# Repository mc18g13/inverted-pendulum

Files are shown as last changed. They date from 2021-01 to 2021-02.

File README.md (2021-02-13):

# rotary-inverted-pendulum



A learning aid for control system design. A rotary inverted pendulum designed with 3d printable frame.

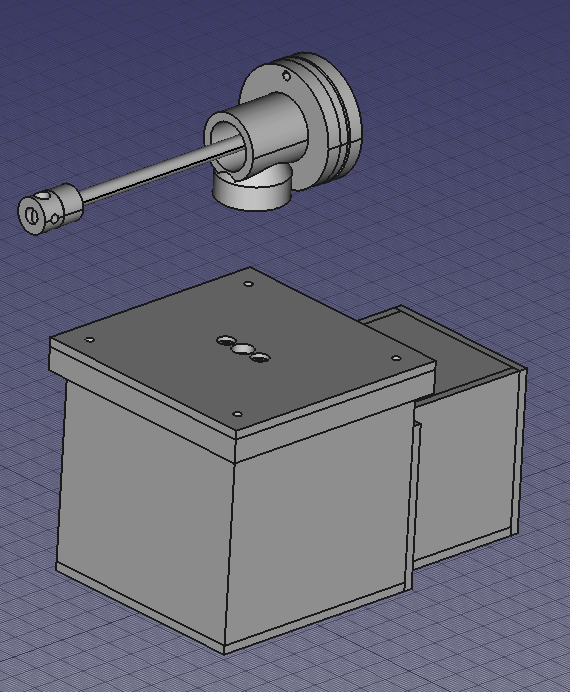
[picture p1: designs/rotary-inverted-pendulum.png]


## Hardware

* Raspberry Pico
* CQRobot 11.7:1 Metal Gearmotor
* L298N motor driver
* AS5600 magnetic encoder
* 5mm diameter steel rod 20cm
* 2 * 625-2RS 5x16x5mm Bearing
* 4 * M3 bolts (box lid)
* 2 * M3 bolts (encoder mount)
* 2 * M3 bolts (pendulum arm mount)
* 2 * M2.5 bolts (motor mount)
* 2 * M4 bolts and nuts (box body mount)
* 3mm flange motor coupling (22mm diameter with 4 M3 bolts)
* Male to Female and Female to Female Jumper wires

# Pico Firmware

This uses docker to setup an image with the required dependencies for building the firmware. Its driven by targets in a makefile as described below

## First Time Setup

This will setup the docker container for building the firmware

```
make
```

## Build
```
make build
```

## Upload
```
make upload
```

## Connect over usb
```
make usb
```

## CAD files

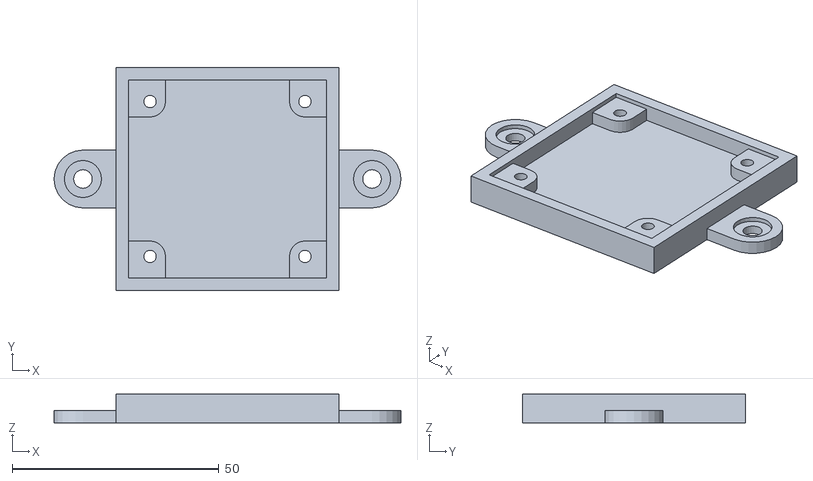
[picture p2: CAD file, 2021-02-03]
designs/cad/l298n/H-Bridge_Mount.stl
84.0 x 54.0 x 7.00

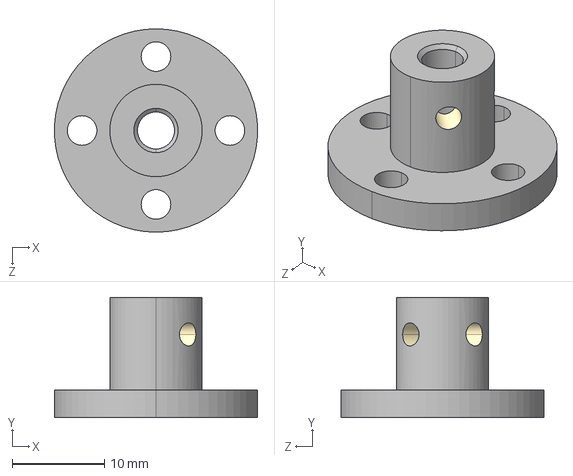
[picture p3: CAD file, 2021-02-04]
designs/cad/motor-coupling/Aluminum Alloy Flange Coupling, 4 mm SHAFT HOLE.STEP
22.0 x 13.0 x 22.0 mm

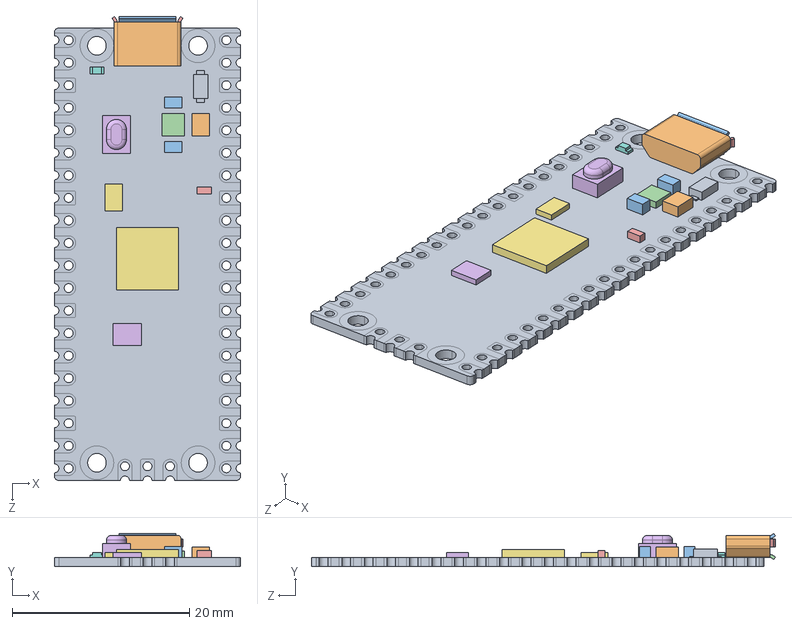
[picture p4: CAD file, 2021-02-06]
designs/cad/pico/Pico-R3.step
21.0 x 3.73 x 52.3 mm
PICO_REF_BOARD.STEP
PICO_REF_USB.STEP
PICO_REF_SWITCH.STEP
PICO_REF_MICROCONTROLLER.STEP
PICO_REF_LED.STEP
PICO_REF_ONSEMI.STEP
PICO_BOURNS.STEP
PICO_MURATA.STEP x 2
PICO_RICHTEK.STEP
PICO_DIODES.STEP
PICO_AEL.STEP
PICO_WINBOND.STEP

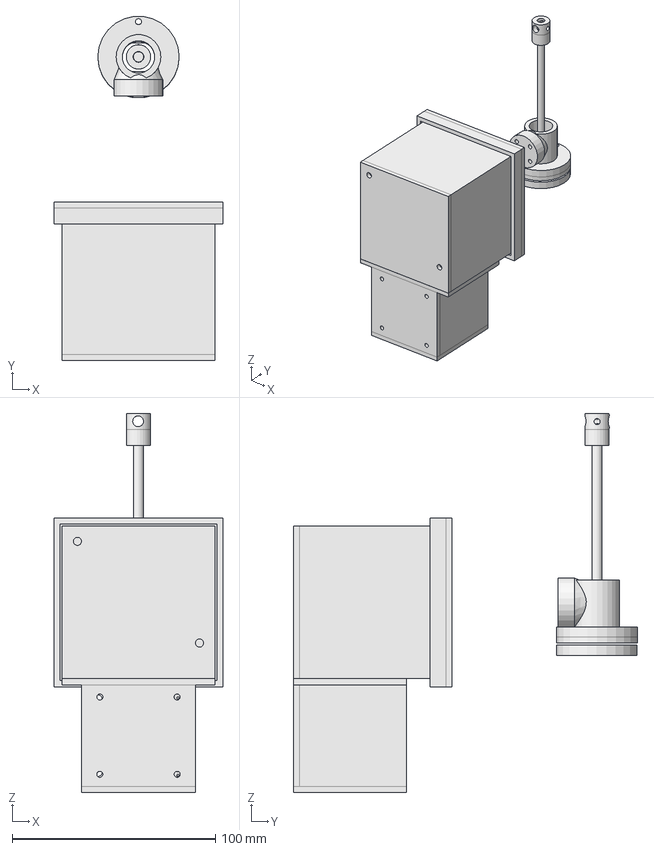
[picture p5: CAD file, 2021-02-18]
designs/cad/rotary-inverted-pendulum.FCStd
83.0 x 169.1 x 186.4 mm
box-lid
motor-box
electronics
motor-arm-connector
L298N_M
PICO_REF_BOARD.STEP

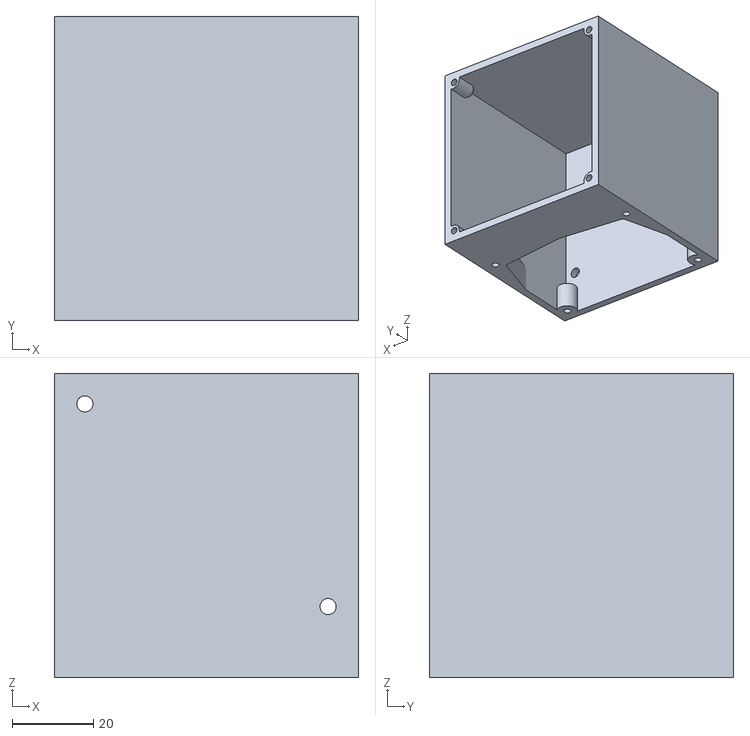
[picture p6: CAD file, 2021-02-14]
designs/cad/motor-box.stl
75.0 x 75.0 x 75.0

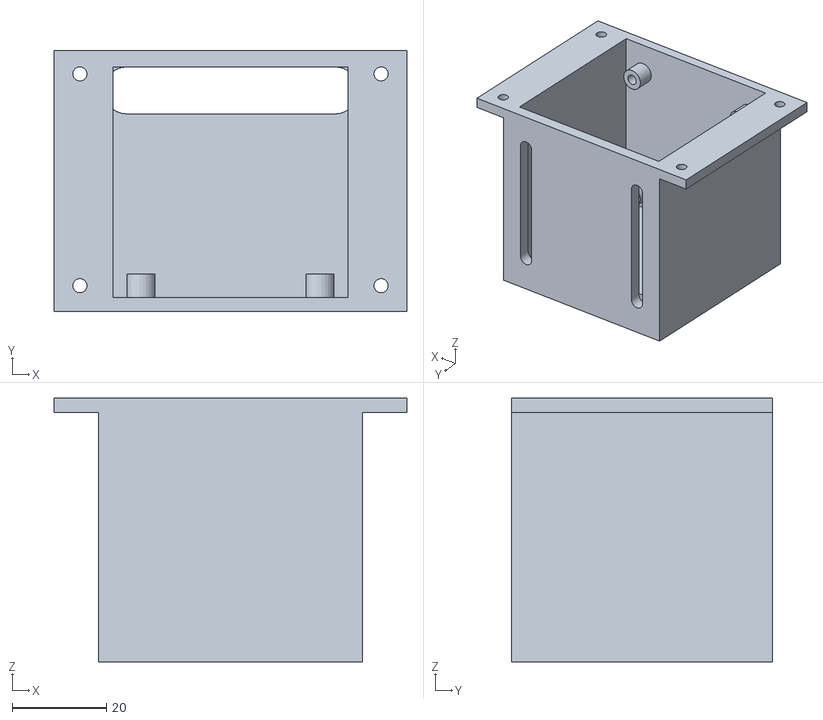
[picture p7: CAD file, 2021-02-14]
designs/cad/electronics-case.stl
75.0 x 55.5 x 56.0

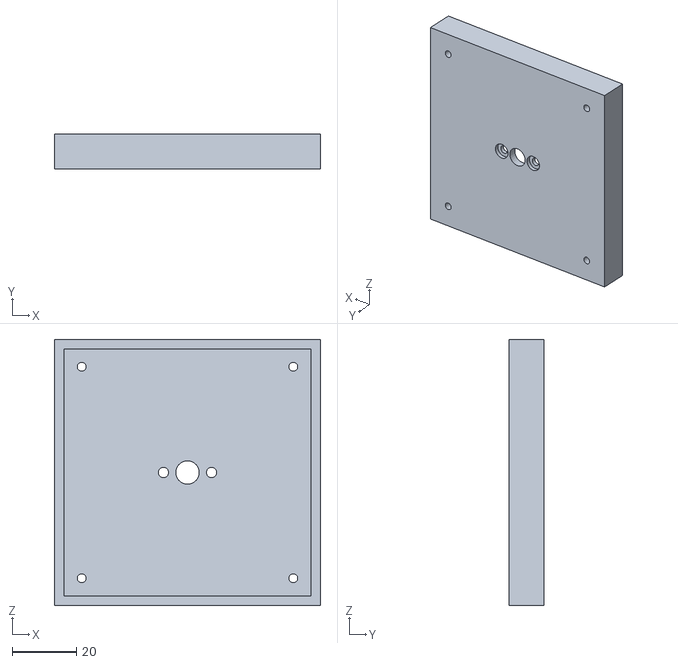
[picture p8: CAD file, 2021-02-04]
designs/cad/dc-motor-lid.stl
83.0 x 11.0 x 83.0

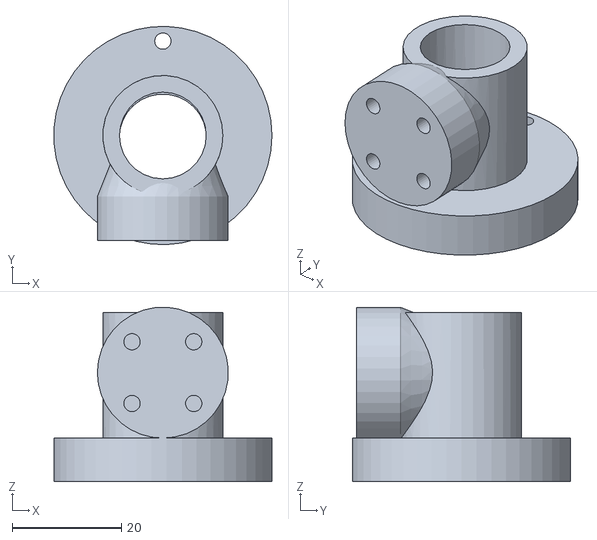
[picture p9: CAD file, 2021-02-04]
designs/cad/motor-arm-connector.stl
40.0 x 40.0 x 32.0

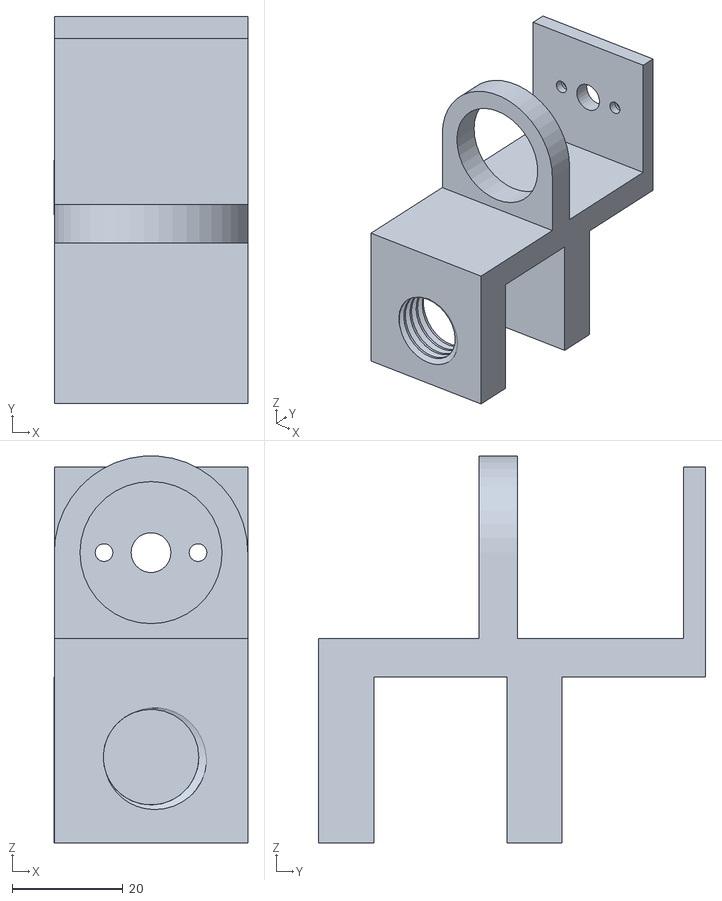
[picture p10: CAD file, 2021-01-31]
designs/cad/dc-motor-mount.stl
35.0 x 70.0 x 70.0

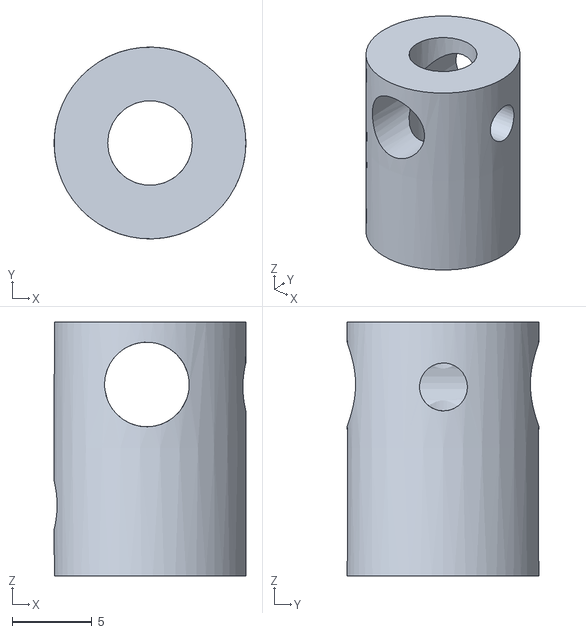
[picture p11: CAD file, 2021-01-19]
designs/cad/pendulum-mount.stl
12.0 x 12.0 x 15.9

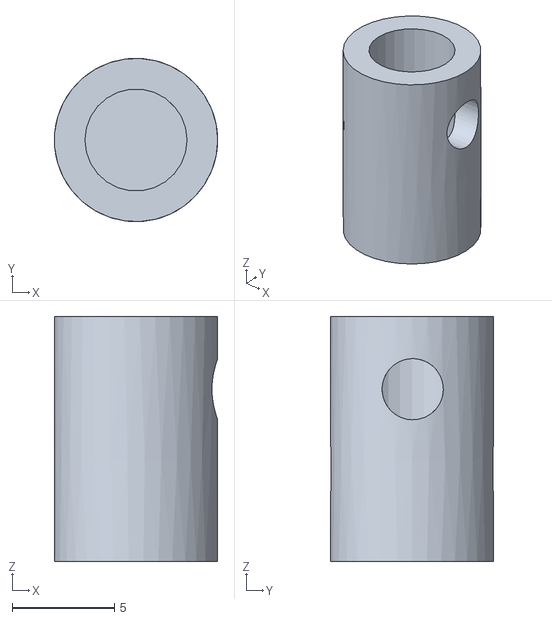
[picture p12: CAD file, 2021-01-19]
designs/cad/magnet-holder.stl
8.00 x 7.99 x 12.0

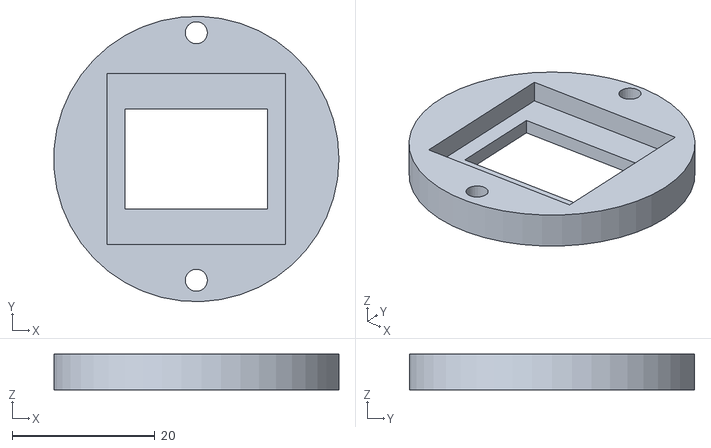
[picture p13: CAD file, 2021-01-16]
designs/cad/encoder-mount.stl
40.0 x 40.0 x 5.00

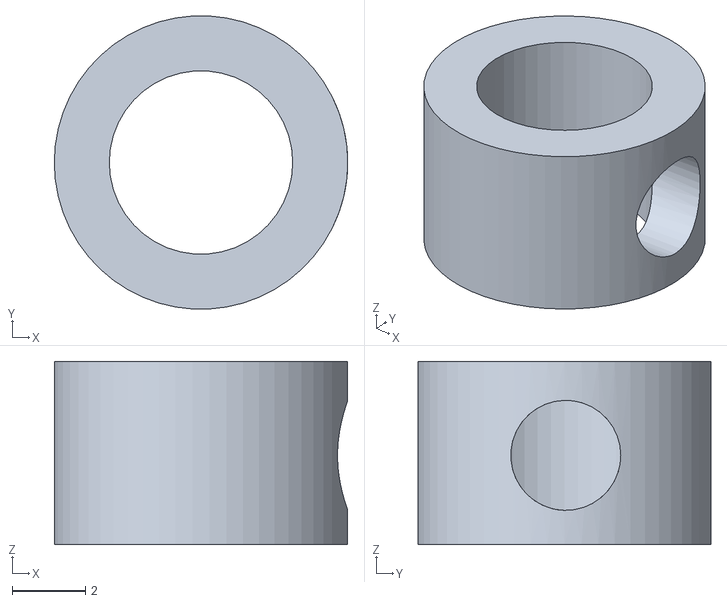
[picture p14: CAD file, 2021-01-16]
designs/cad/stopper.stl
8.00 x 7.99 x 5.00

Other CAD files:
designs/cad/box.stl

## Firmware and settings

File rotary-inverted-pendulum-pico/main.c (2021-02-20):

#include <stdio.h>

#include "pico/stdlib.h"
#include "hardware/gpio.h"
#include "motor_driver.h"
#include "motor_encoder.h"
#include "arm_encoder.h"
#include "pid_controller.h"
#include "math.h"
#include "arm_math.h"

const float32_t K_f32[4] = 
{
// -31.623,  300.061,    -23.925,     11.273
-10.0000,   108.3142,   -3.9802,    1.9517
};

float32_t input_U_f32[4];

float32_t output_X_f32[4];

#define SNR_THRESHOLD   90

#define LED_PIN 25
void setup_on_board_led() {
  gpio_init(LED_PIN);
  gpio_set_dir(LED_PIN, GPIO_OUT);
}

void toggle_on_board_led() {
  gpio_put(LED_PIN, !gpio_get(LED_PIN));
}

int main() {
    stdio_init_all();
    setup_on_board_led();
    setup_motor_driver();
    setup_motor_encoder();
    setup_arm_encoder();
    toggle_on_board_led();

    calibrate_arm_encoder();

    const float fifteen_degrees_as_rads = 30.0f * M_PI / 180.0f;

    float previous_pendulum_angle = get_arm_encoder_angle();
    float current_pendulum_angle;
    float current_pendulum_speed;

    float previous_motor_angle = get_motor_displacement_radians();
    float current_motor_angle;
    float current_motor_speed;

    absolute_time_t previous_time_us = get_absolute_time();
    absolute_time_t current_time_us = get_absolute_time();
    absolute_time_t delta_time_us;

    while (1) {
      current_time_us = get_absolute_time();
      delta_time_us = current_time_us - previous_time_us;
      previous_time_us = current_time_us;


      current_pendulum_angle = get_arm_encoder_angle();
      current_motor_angle = get_motor_displacement_radians();
      // printf("current_pendulum_angle %f\n", current_pendulum_angle);
      // printf("current_motor_angle %f\n", current_motor_angle);
      // Possible add deadband around balance point
      if (fabs(current_pendulum_angle) < fifteen_degrees_as_rads) {

        float time_s = (float)delta_time_us / 1000000.0f;
        current_pendulum_speed = (current_pendulum_angle - previous_pendulum_angle) / time_s;
        current_motor_speed = (current_motor_angle - previous_motor_angle) / time_s;

        // printf("current_motor_speed %f\n", current_pendulum_angle);
        // printf("current_pendulum_speed %f\n", current_pendulum_speed);
        float32_t output = K_f32[0] * current_motor_angle + K_f32[1] * current_pendulum_angle + K_f32[2] * current_motor_speed + K_f32[3] * current_pendulum_speed; 
        uint output_absolute = (uint)fabs(output);
        // output_absolute = (output_absolute * output_absolute);
        // printf("output_absolute %d \n", output_absolute);
        // printf("%f %f %f %f %f %f\n",time_s ,current_motor_angle , current_pendulum_angle, current_motor_speed, current_pendulum_speed, output);

        if (output > 0) {
          run_motor(CLOCKWISE, output_absolute);
        } else {
          run_motor(ANTI_CLOCKWISE, output_absolute);
        }

      } else {
        stop_motor();
      }

      previous_pendulum_angle = current_pendulum_angle;
      previous_motor_angle = current_motor_angle;


      // sleep_ms(10);
    }

    return 0;
}

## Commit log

2021-01-16 first commit, state finding equations with sympy, DRV8825 driver code
2021-01-16 finish control, add cad files, ignore build files
    [box.stl, encoder-mount.stl, inverted-pendulum.FCStd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]
2021-01-19 setup designs for dc motor
    [12v22rpm.SLDPRT, Getriebe-Motor 12V.STEP, User Library-eBay DC Geared Motor 6V 1000RPM.STEP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]
2021-01-25 movement and testing with dc motor
    [inverted-pendulum.FCStd, motor-arm-connector.stl]
2021-01-31 add design for dc motor table mount
    [dc-motor-mount.stl, inverted-pendulum.FCStd, motor-arm-connector.stl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]
2021-01-31 move motor mount back to box design
    [inverted-pendulum.FCStd]
2021-02-03 improvements to motor arm mount and unused cad files
    [12v22rpm.SLDPRT, Getriebe-Motor 12V.STEP, H-Bridge_Mount.stl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]
2021-02-04 update designs for new motor and replace arduino with raspi pico
    [Aluminum Alloy Flange Coupling, 4 mm SHAFT HOLE.STEP, dc-motor-lid.stl, inverted-pendulum.FCStd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]
2021-02-04 add setup example project with raspiberry pico
2021-02-04 begin adding debug for pico
2021-02-05 add i2c script
2021-02-05 attach workspace in circle config to use checked out code
2021-02-05 correct attaching workspace for circle
2021-02-05 add submodule update for pico lib
2021-02-05 only update pico sdk submodule
2021-02-06 rename pico code directory
2021-02-06 rename cad files
    [rotary-inverted-pendulum.FCStd]
2021-02-06 remove unused cad design
2021-02-06 add continuous i2c scanning script
2021-02-06 add pico step file for designs and add app to read rotary encoder
    [Pico-R3.step, inverted-pendulum.FCStd]
2021-02-08 clean up for beginning motor driver
2021-02-11 add motor encoder lib, design cad image and update arm encoder
    [box.stl, motor-mount-table-screw.stl, rotary-inverted-pendulum.FCStd]
2021-02-11 add cased for l298n and update image
    [rotary-inverted-pendulum.FCStd]
2021-02-14 add electronics case and update motor housing
    [electronics-case.stl, motor-box.stl, rotary-inverted-pendulum.FCStd]
2021-02-16 add cmsis, matrix example and pwm control for motor
2021-02-18 update system model scripts
    [rotary-inverted-pendulum.FCStd]
